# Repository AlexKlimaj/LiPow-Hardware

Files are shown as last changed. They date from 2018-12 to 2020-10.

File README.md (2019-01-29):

# USB-PD-Lipo-Charger-Hardware

https://hackaday.io/project/161771-usb-power-delivery-lipo-battery-charger

This project uses USB Type C with Power Delivery to charge Lithium Polymer batteries. It supports charging 1s-4s batteries and supports balancing for 2s-4s packs. The device supports charging up to 100W (16.8V at 6A).

I got the idea for this project while on a vacation where I only took a single 65W USB C power supply from my Thinkpad to charge the laptop, Nintendo Switch, and cell phone. Having worked with hobby style lithium polymer batteries and bulky chargers, I thought it would be nice to have a small device that could charge LiPo batteries from a USB C power supply.

Input is a USB Type C Port. Charging is done through an XT60 connector and has JST connectors for balancing 2s-4s packs.

The device will be pre-programmed with a fixed max current limit up to 6A. Everything runs automatically and will charge up to the max capability of the connected USB PD power supply if the max current output limit exceeds the input power supply.

The only user feedback is through an RGB LED.

A STM32G0 microcontroller controls runs the system and handles USB PD communication. TI makes the perfect programmable buck boost regulator for this project with the BQ25703A. It accepts input voltage from 3.5V to 24V and the output is meant to charge lithium batteries up to 4s with a current limit of 6.35A. It is programmed through I2C.

A 3.3V linear regulator was needed to provide power for the electronics. The hardest part is that it needs to accept up to 20V on the input due to the power delivery specifications. The IFX25001 from Infineon accepts up to 45V and is a good fit for the project.

I chose to have balance ports for 2s-4s packs for balancing with charging done through an XT60 connector. Originally I was going to support charging through the balance ports, but the typical gauge of wire used for those connections would severely limit the charging current. I also had to design a circuit to automatically route the output from the regulator to the top cell depending on what type of pack was connected. I designed the circuit and thought it was pretty clever, but ultimately, made the decision to reduce complexity and support higher charging current by going with an XT60 connector.

Balancing is controlled by the STM32G0. It monitors the cell voltages using its ADC through voltage dividers to scale the voltage to safe levels. Open drain level shifters were needed to control the PFETs used for discharging. Because of this, it create a large VGS on the PFETs, up to the max of a 4s pack ~16.8V. I needed to find PFETs that could handle 20V VGS.

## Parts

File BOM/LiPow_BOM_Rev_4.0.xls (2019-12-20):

LibRef | Designator | Quantity | Manufacturer | Mfr Part Number | Comment | Mfr Part Description | Footprint | Supplier | Supplier Part Number
30220 | C2, C4, C8, C12, C13, C14, C15, C17, C18, C19, C20, C21, C22, C23, C30, C31, C32, C33, C34, C35, C36, C37 | 22 | TDK Corporation | C2012X5R1V106M085AC | 10uF | CAP CER 10uF ±20% 35V X5R 0805 (2012 Metric) | CAPC0805(2012)155_N | Digi-Key | 445-14419-1-ND
30222 | C5, C9, C38, C40, C47, C48, C49, C50, C51 | 9 | Samsung Electro-Mechanics | CL21B105KBFNNNG | 1uF | CAP CER 1uF ±10% 50V X7R 0805 (2012 Metric) | CAPC0805(2012)155_N | Digi-Key | 1276-6470-1-ND
30221 | C10, C16, C39 | 3 | Samsung Electro-Mechanics | CL21B104KCFNNNE | 0.1uF | CAP CER 0.1uF ±10% 100V X7R 0805 (2012 Metric) | CAPC0805(2012)155_N | Digi-Key | 1276-6840-1-ND
30250 | C24, C25 | 2 | KEMET | C0805C333J3RACTU | 0.033uF | CAP CER 0.033uF ±5% 25V X7R 0805 (2012 Metric) | CAPC0805(2012)155_N | Digi-Key | 399-8069-1-ND
30253 | C26, C27 | 2 | Walsin Technology Corporation | 0805B473J500CT | 0.047uF | CAP CER 0.047uF ±5% 50V X7R 0805 (2012 Metric) | CAPC0805(2012)155_N | Digi-Key | 1292-1583-1-ND
30257 | C41 | 1 | Samsung Electro-Mechanics | CL21A225KAFNNNG | 2.2uF | CAP CER 2.2uF ±10% 25V X5R 0805 (2012 Metric) | CAPC0805(2012)155_N | Digi-Key | 1276-6458-1-ND
30258 | C42 | 1 | Samsung Electro-Mechanics | CL21C330JBANNNC | 33pF | CAP CER 33pF ±5% 50V NPO 0805 (2012 Metric) | CAPC0805(2012)155_N | Digi-Key | 1276-1105-1-ND
30259 | C43 | 1 | Samsung Electro-Mechanics | CL21B182KBANNNC | 1800pF | CAP CER 1800pF ±10% 50V X7R 0805 (2012 Metric) | CAPC0805(2012)155_N | Digi-Key | 1276-2465-1-ND
30262 | C44 | 1 | Wurth Electronics Inc. | 885012007029 | 15pF | CAP CER 15pF ±5% 25V NPO 0805 (2012 Metric) | CAPC0805(2012)155_N | Digi-Key | 732-7828-1-ND
30261 | C45 | 1 | Samsung Electro-Mechanics | CL21B681KBANNNC | 680pF | CAP CER 680pF ±10% 50V X7R 0805 (2012 Metric) | CAPC0805(2012)155_N | Digi-Key | 1276-2538-1-ND
30264 | C46 | 1 | Samsung Electro-Mechanics | CL21C101JC61PNC | 100pF | CAP CER 100pF ±5% 100V NPO 0805 (2012 Metric) | CAPC0805(2012)155_N | Digi-Key | 1276-2569-1-ND
30239 | D1, D2, D4, D5, D6, D7, D8 | 7 | ON Semiconductor | ESD9X5.0ST5G | ESD9X5.0ST5G | TVS DIODE 5V 12.3V SOD923 | SOD-923 | Digi-Key | ESD9X5.0ST5GOSCT-ND
30242 | D3 | 1 | Everlight Electronics Co Ltd | EAST1616RGBA3 | EAST1616RGBA3 | LED RGB CLEAR 4SMD | EAST1616RGBA3 | Digi-Key | 1080-1550-1-ND
30231 | F1 | 1 | Vishay Beyschlag | MFU0603FF05000P100 | MFU0603FF05000P100 | FUSE BOARD MOUNT 5A 32VDC 0603 | Fuse 0603 | Digi-Key | MFU06035.00CT-ND
30530 | J1 | 1 | Molex | 2012670005 | 2012670005 | CONN RCP USB3.1 TYPEC 24P SMD RA | 2012670005 | Digi-Key | WM17992CT-ND
30040 | J2 | 1 | JST Sales America Inc. | S5B-XH-A(LF)(SN) | S5B-XH-A 5 Pin Header | CONN HEADER XH SIDE 5POS 2.5MM | S5B-XH-A | Digi-Key | 455-2242-ND
30228 | J3 | 1 | JST Sales America Inc. | S4B-XH-A(LF)(SN) | S4B-XH-A(LF)(SN) | CONN HEADER XH SIDE 4POS 2.5MM | S4B-XH-A | Digi-Key | 455-2243-ND
30229 | J4 | 1 | JST Sales America Inc. | S3B-XH-A(LF)(SN) | S3B-XH-A(LF)(SN) | CONN HEADER XH SIDE 3POS 2.5MM | S3B-XH-A | Digi-Key | 455-2250-ND
30265 | J6 | 1 | AMASS | XT60PW-M | XT60PW-M | Socket; DC supply; XT60; male; PIN:2; on PCBs; THT; Colour: yellow | XT60PW-M | tme.eu | XT60PW-M
30252 | L1 | 1 | Murata Electronics North America | DD1217AS-H-2R2N=P3 | 2.2uH | INDUCTOR 2.2uH ±30% 8.7A Nonstandard | DD1217AS-H-2R2N=P3 | Digi-Key | 490-13196-1-ND
30266 | Q1, Q3, Q4, Q5, Q6 | 5 | Diodes Incorporated | DMP3056L-7 | Vgs(max)=+-25V | MOSFET P-CH 30V 4.3A SOT23 | Diode SOT23 PMOS | Digi-Key | DMP3056L-7DICT-ND
30255 | Q2 | 1 | Micro Commercial Co | MCQ4435-TP | MCQ4435-TP | P-CHANNEL MOSFET, SOP-8 PACKAGE | SOP-8 PMOS Micro Commercial | Digi-Key | MCQ4435-TPMSCT-ND
30247 | Q8, Q9, Q10, Q11 | 4 | Nexperia USA Inc. | NX7002AK,215 | NX7002AK,215 | MOSFET N-CH 60V TO-236AB | TO-236AB (SOT23) | Digi-Key | 1727-1289-1-ND
30251 | Q12, Q13, Q14, Q15 | 4 | Rohm Semiconductor | RQ3E080BNTB | RQ3E080BNTB | MOSFET N-CH 30V 8A HSMT8 | RQ3E080BNTB | Digi-Key | RQ3E080BNTBCT-ND
30227 | R1, R5, R6, R7, R8, R18, R25, R27, R29, R31, R36, R37, R38, R39, R50, R51, R53, R57 | 18 | Bourns Inc. | CR0805-FX-1002ELF | 10K | RES 10K Ohm ±1% 1/8W 0805 (2012 Metric) | RESC0805(2012)_L | Digi-Key | CR0805-FX-1002ELFCT-ND
30236 | R3, R4, R13, R14, R15, R20 | 6 | TE Connectivity Passive Product | CRGCQ0805F1K2 | 1.2K | RES 1.2K Ohm ±1% 1/8W 0805 (2012 Metric) | RESC0805(2012)_L | Digi-Key | A129750CT-ND
30294 | R9, R12, R19 | 3 | Stackpole Electronics Inc. | RMCF0805FG5K36 | 5.36K | RES 5.36K Ohm ±1% 1/8W 0805 (2012 Metric) | RESC0805(2012)_L | Digi-Key | RMCF0805FG5K36CT-ND
30295 | R10 | 1 | Stackpole Electronics Inc. | RMCF0805FT3K57 | 3.57K | RES 3.57K Ohm ±1% 1/8W 0805 (2012 Metric) | RESC0805(2012)_L | Digi-Key | RMCF0805FT3K57CT-ND
30238 | R11, R21, R44, R56, R58 | 5 | Bourns Inc. | CR0805-J/-000ELF | 0 | RES 0 Ohm Jumper 1/8W 0805 (2012 Metric) | RESC0805(2012)_L | Digi-Key | CR0805-J/-000ELFCT-ND
30235 | R16, R17 | 2 | Stackpole Electronics Inc. | RMCF0805FT3K30 | 3.3K | RES 3.3K Ohm ±1% 1/8W 0805 (2012 Metric) | RESC0805(2012)_L | Digi-Key | RMCF0805FT3K30CT-ND
30439 | R26, R28, R30, R32 | 4 | Rohm Semiconductor | LTR18EZPJ470 | 47 | RES SMD 47 OHM 3/4W 1206 WIDE | Wide 1206 (3216 Metric) | Digi-Key | RHM47ZCT-ND
30243 | R33 | 1 | Stackpole Electronics Inc. | RMCF0805JT300R | 300 | RES 300 Ohm ±5% 1/8W 0805 (2012 Metric) | RESC0805(2012)_L | Digi-Key | RMCF0805JT300RCT-ND
30244 | R34 | 1 | Stackpole Electronics Inc. | RMCF0805JT75R0 | 75 | RES 75 Ohm ±5% 1/8W 0805 (2012 Metric) | RESC0805(2012)_L | Digi-Key | RMCF0805JT75R0CT-ND
30245 | R35 | 1 | Bourns Inc. | CR0805-JW-101ELF | 100 | RES 100 Ohm ±5% 1/8W 0805 (2012 Metric) | RESC0805(2012)_L | Digi-Key | CR0805-JW-101ELFCT-ND
30248 | R40, R41 | 2 | Ohmite | LVT12R0100FER | 0.01 | RES 0.01 Ohm ±1% 1W 1206 (3216 Metric) | RES1206 | Digi-Key | LVT12R0100FERCT-ND
30249 | R42, R43 | 2 | Stackpole Electronics Inc. | RMCF0805FT4R99 | 4.99 | RES 4.99 Ohm ±1% 1/8W 0805 (2012 Metric) | RESC0805(2012)_L | Digi-Key | RMCF0805FT4R99CT-ND
30256 | R45, R46, R47, R49 | 4 | Stackpole Electronics Inc. | RMCF0805FT10R0 | 10 | RES 10 Ohm ±1% 1/8W 0805 (2012 Metric) | RESC0805(2012)_L | Digi-Key | RMCF0805FT10R0CT-ND
30260 | R52, R54 | 2 | Yageo | RC0805FR-0740K2L | 40.2K | RES 40.2K Ohm ±1% 1/8W 0805 (2012 Metric) | RESC0805(2012)_L | Digi-Key | 311-40.2KCRCT-ND
30263 | R55 | 1 | Stackpole Electronics Inc. | RMCF0805FT137K | 137K | RES 137K Ohm ±1% 1/8W 0805 (2012 Metric) | RESC0805(2012)_L | Digi-Key | RMCF0805FT137KCT-ND
30269 | U2 | 1 | STMicroelectronics | STM32G071CBT6 | STM32G071CBT6 | MAINSTREAM ARM CORTEX-M0+ MCU WI | ST LQFP48 | Digi-Key | 497-18342-ND
30225 | U3 | 1 | Texas Instruments | BQ25703ARSNR | BQ25703ARSNR | BQ25703ARSNR | QFN40P400X400X80_HS-33N | Digi-Key | 296-47649-1-ND
30240 | U5 | 1 | Infineon Technologies | IFX25001MEV33HTSA1 | IFX25001MEV33HTSA1 | IC REG LIN 3.3V 400MA SOT223-4 | PG-SOT223-4 Infineon | Digi-Key | IFX25001MEV33HTSA1CT-ND

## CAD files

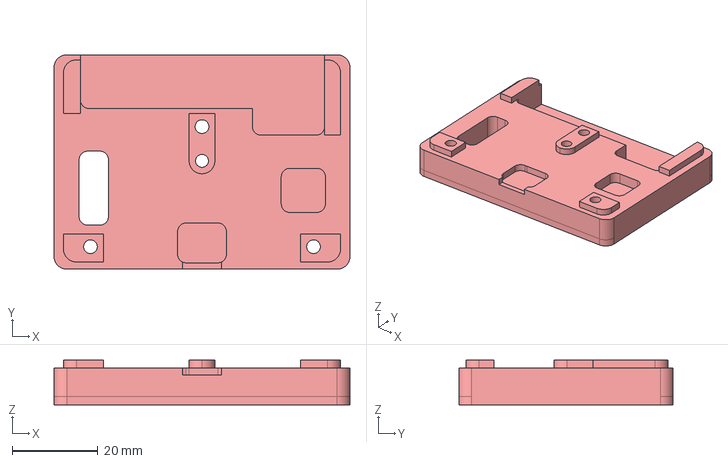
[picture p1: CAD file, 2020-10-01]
Case/CNC Case/Top Case CNC V1.0.step
69.0 x 50.0 x 10.4 mm

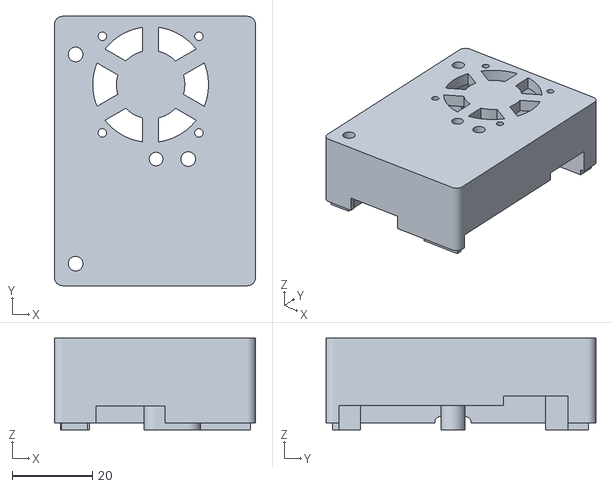
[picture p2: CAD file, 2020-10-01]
Case/Fan Case/Top Case Fan 1.0.stl
50.0 x 67.0 x 22.8

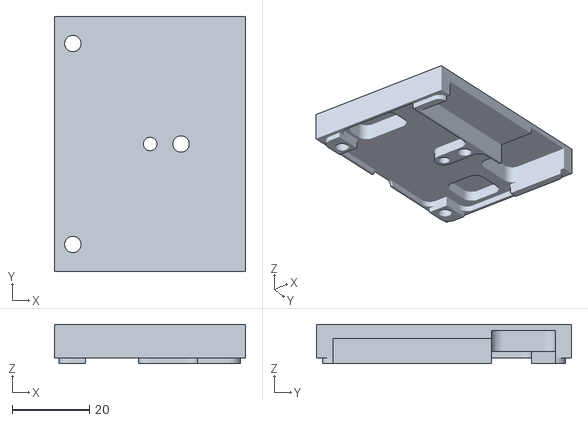
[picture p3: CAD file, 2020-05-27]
Case/Regular Case/LiPow Top Case Rev 0.6.stl
49.5 x 66.0 x 10.2

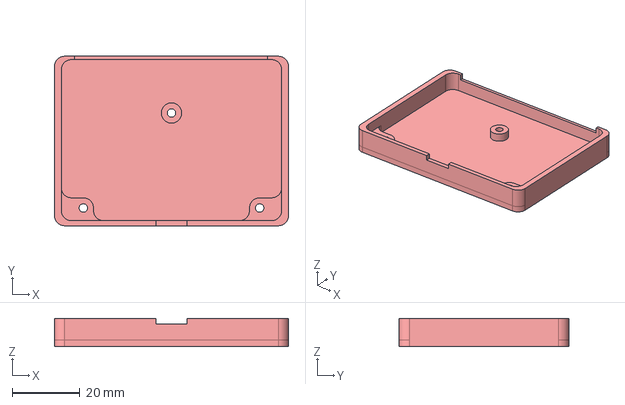
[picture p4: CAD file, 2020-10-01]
Case/CNC Case/Bottom Case CNC V1.0.step
69.0 x 50.0 x 8.31 mm

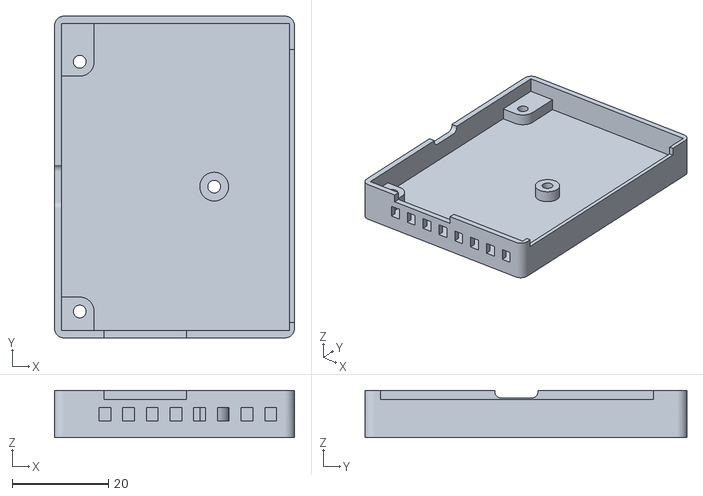
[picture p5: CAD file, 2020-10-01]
Case/Fan Case/Bottom Case Fan 1.0.stl
50.0 x 67.0 x 9.81

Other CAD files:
Case/Regular Case/LiPow Bottom Case Rev 0.6.stl
Case/Regular Case/LiPow Top Case Rev 0.5 Debug.stl

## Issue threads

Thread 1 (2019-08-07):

Break out VSYS?

nevercast, 2019-08-07:
Hello Alex,

I really like this board design and I've checked out your product on Tindie. The BQ25703ARSNR is a very nice chip too.

I'm hoping you might consider another product, or a revision to this product, where VSYS is provided on a board header also so that I may use LiPow as both a charger and power delivery to my system.

I would like to use something similar to LiPow for in-system charging of my robot project as well as powering the system. The BQ25703ARSNR has some nice features included powering the system from charge cable and supplimenting with battery power when available.

Since the STM32G0 occupies the I2C and having two hosts talk to the BQ25703ARSNR could be bad, I would consider making the UART protocol machine readable, but that would be a software adaption and I see that is open source.

Do you have any plans in the future to provide system power from the LiPow?

Thanks again for your time on this project, it really is a nicely done board.

AlexKlimaj, 2019-08-08:
Hi, thanks for the feedback. I don't have any plans at the moment for a revision of LiPow. I do have a board I've designed that is purely a breakout for the BQ25703ARSNR. It is sitting in a box waiting to be assembled. Unfortunately I didn't break out VSYS on that either. But there are lots of bulk capacitors on VSYS you could tack onto. Same with LiPow.
https://github.com/AlexKlimaj/BQ25703A_Module

It would be pretty easy to improve the firmware to have everything controllable over the UART.

nevercast, 2019-08-11:
Hello again Alex,

Thanks for the link to your breakout board. Are the only board layout files in the manufacturing docs? Do you have gerbers?

Kind regards

AlexKlimaj, 2019-08-12:
I can send you the gerbers if you are interested in building your own. I could also send you PCBs if you are interested.

nevercast, 2019-08-12:
I would be interested in building my own, and probably merging the module with existing hardware that I have for driving motors / servos. Shall we continue this via email?

x893, 2020-02-19:
Hello Alex,
Thank you for LiPow and BQ25703 boards design. I want order boards for soldering (i have BQ... and other chips). Can you commit or send me directly gerber files ?

Best regards
Mitek

AlexKlimaj, 2020-02-20:
@x893 send me an email at alex@arkelectron.com

x893, 2020-02-22:
@AlexKlimaj please send to x893.00@gmail.com
Thanks

Closed 2020-02-20.

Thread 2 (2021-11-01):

What different BAT pin and CELL_4S/CELL_3S pin?

jecelyin, 2021-11-01:
Hi,
   I use 3s of 18650 batteries to charge, how to connect is correct?

Thanks!

---------- BAT or CELL_3S ?
🔋
---------- CELL_2S
🔋
---------- CELL_1S
🔋
---------- GND

AlexKlimaj, 2021-11-01:
You need cell 3s connected to the 3s input and BAT to charge. If it is just connected to the balance port, it will only balance.

jecelyin, 2021-11-01:
---------- BAT pin and CELL_3S pin connect to here?
🔋
---------- CELL_2S
🔋
---------- CELL_1S
🔋
---------- GND

AlexKlimaj, 2021-11-02:
That is correct.

jecelyin, 2021-11-02:
Thanks

Closed 2021-11-02.

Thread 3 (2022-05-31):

No Gerber file?

bigjoncoop, 2022-05-31:
I see you have the BOM files but I do not see a gerber file for the PCB...

The schematics or just PDF files. So I'm not quite sure what the purpose of the GitHub is for?

Anyone that's reading this I'll go ahead and spend a bunch of hours recreating the schematics and designing a new pcb and uploads all the files, including a gerber file. If the BOM changes due to the chip shortage at the moment I'll make a note.

AlexKlimaj, 2022-05-31:
Yes that is intentional.

Closed 2022-05-31.

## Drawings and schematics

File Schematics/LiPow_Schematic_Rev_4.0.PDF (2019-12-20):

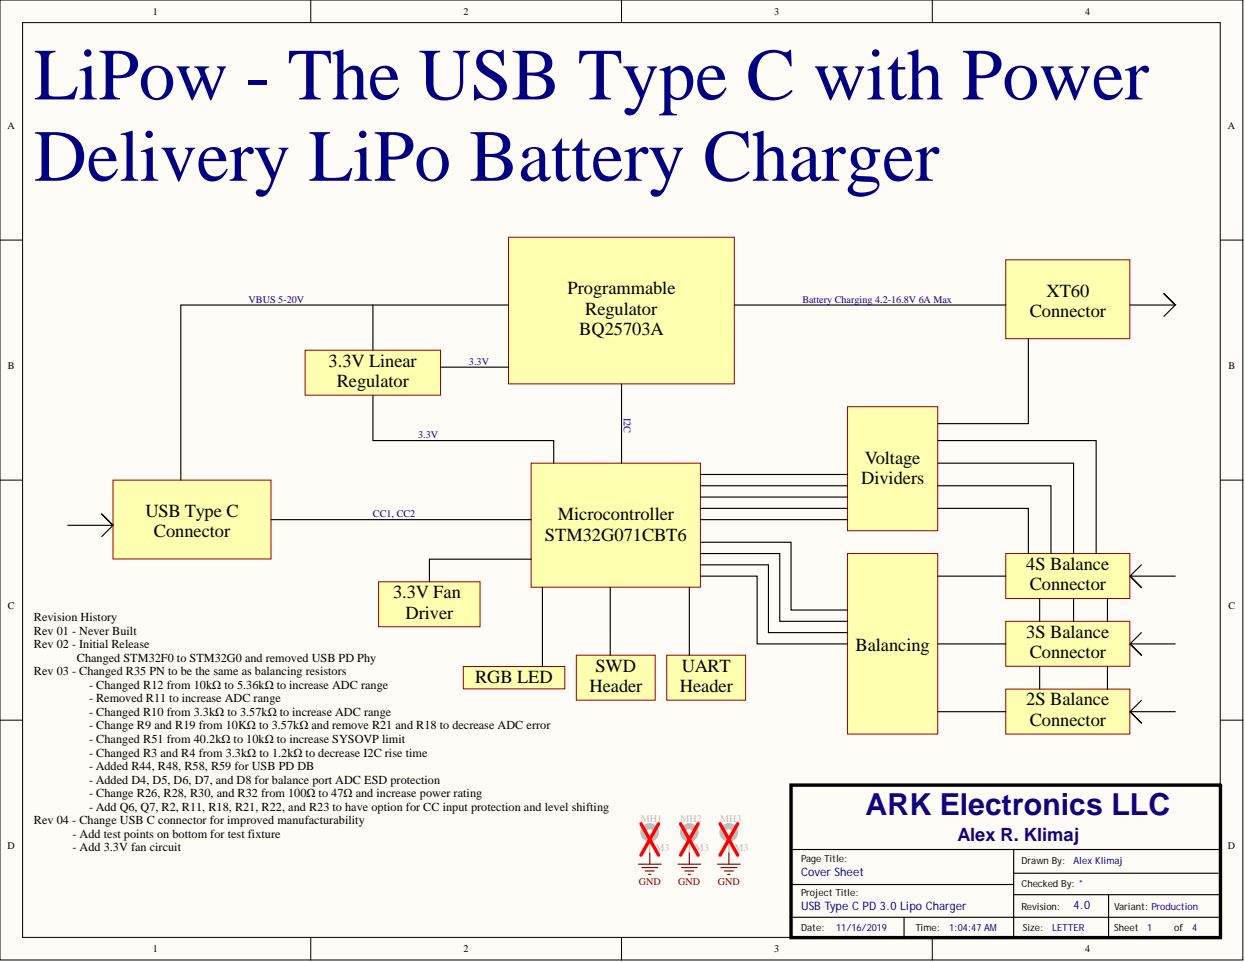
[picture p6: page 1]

LiPow - The USB Type C with Power
Delivery LiPo Battery Charger

Changed STM32F0 to STM32G0 and removed USB PD Phy

Rev 03 - Changed R35 PN to be the same as balancing resistors

- Changed R12 from 10kΩ to 5.36kΩ to increase ADC range
- Removed R11 to increase ADC range
- Changed R10 from 3.3kΩ to 3.57kΩ to increase ADC range
- Change R9 and R19 from 10KΩ to 3.57kΩ and remove R21 and R18 to decrease ADC error
- Changed R51 from 40.2kΩ to 10kΩ to increase SYSOVP limit
- Changed R3 and R4 from 3.3kΩ to 1.2kΩ to decrease I2C rise time
- Added R44, R48, R58, R59 for USB PD DB
- Added D4, D5, D6, D7, and D8 for balance port ADC ESD protection
- Change R26, R28, R30, and R32 from 100Ω to 47Ω and increase power rating
- Add Q6, Q7, R2, R11, R18, R21, R22, and R23 to have option for CC input protection and level shifting

Rev 04 - Change USB C connector for improved manufacturability

- Add test points on bottom for test fixture
- Add 3.3V fan circuit

Project Title:
USB Type C PD 3.0 Lipo Charger

Revision: | Variant: Production

Date: 11/16/2019 | Time: 1:04:47 AM | Size: LETTER | Sheet of

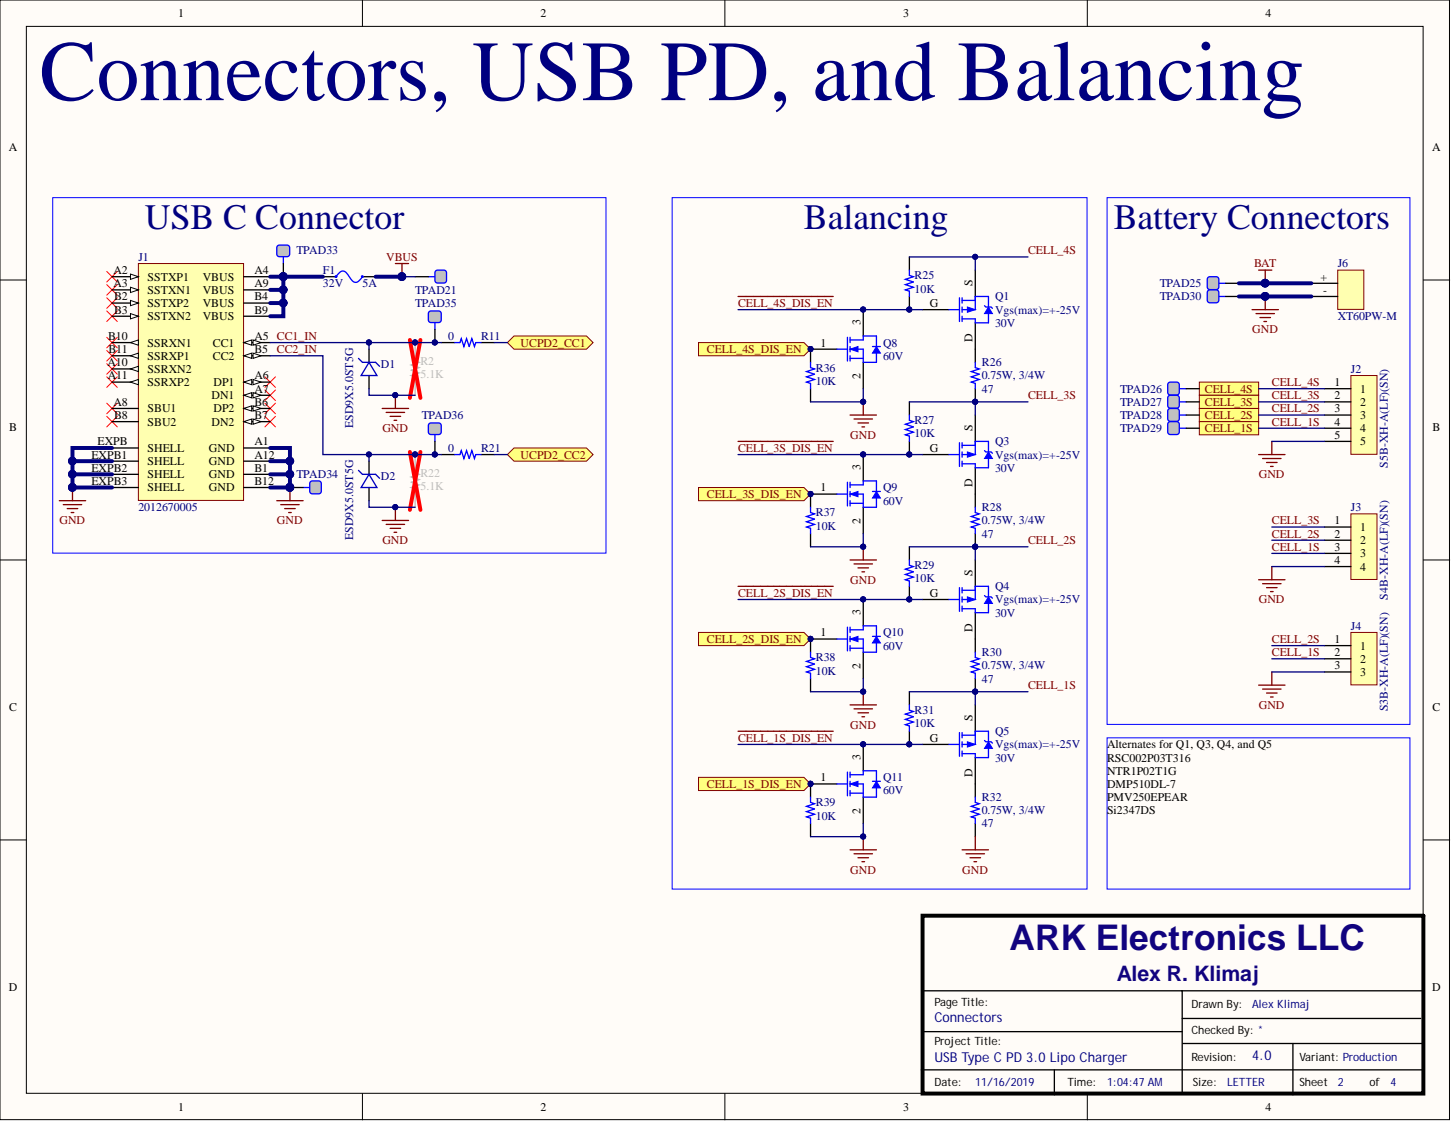
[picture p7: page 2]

Connectors, USB PD, and Balancing

GND
ARK Electronics LLC Alex R. Klimaj

Title:
Type C PD 3.0 Lipo Charger

Variant : Production 2 4

Date: 11/16/2019 | 1:04:47 A M | Size:

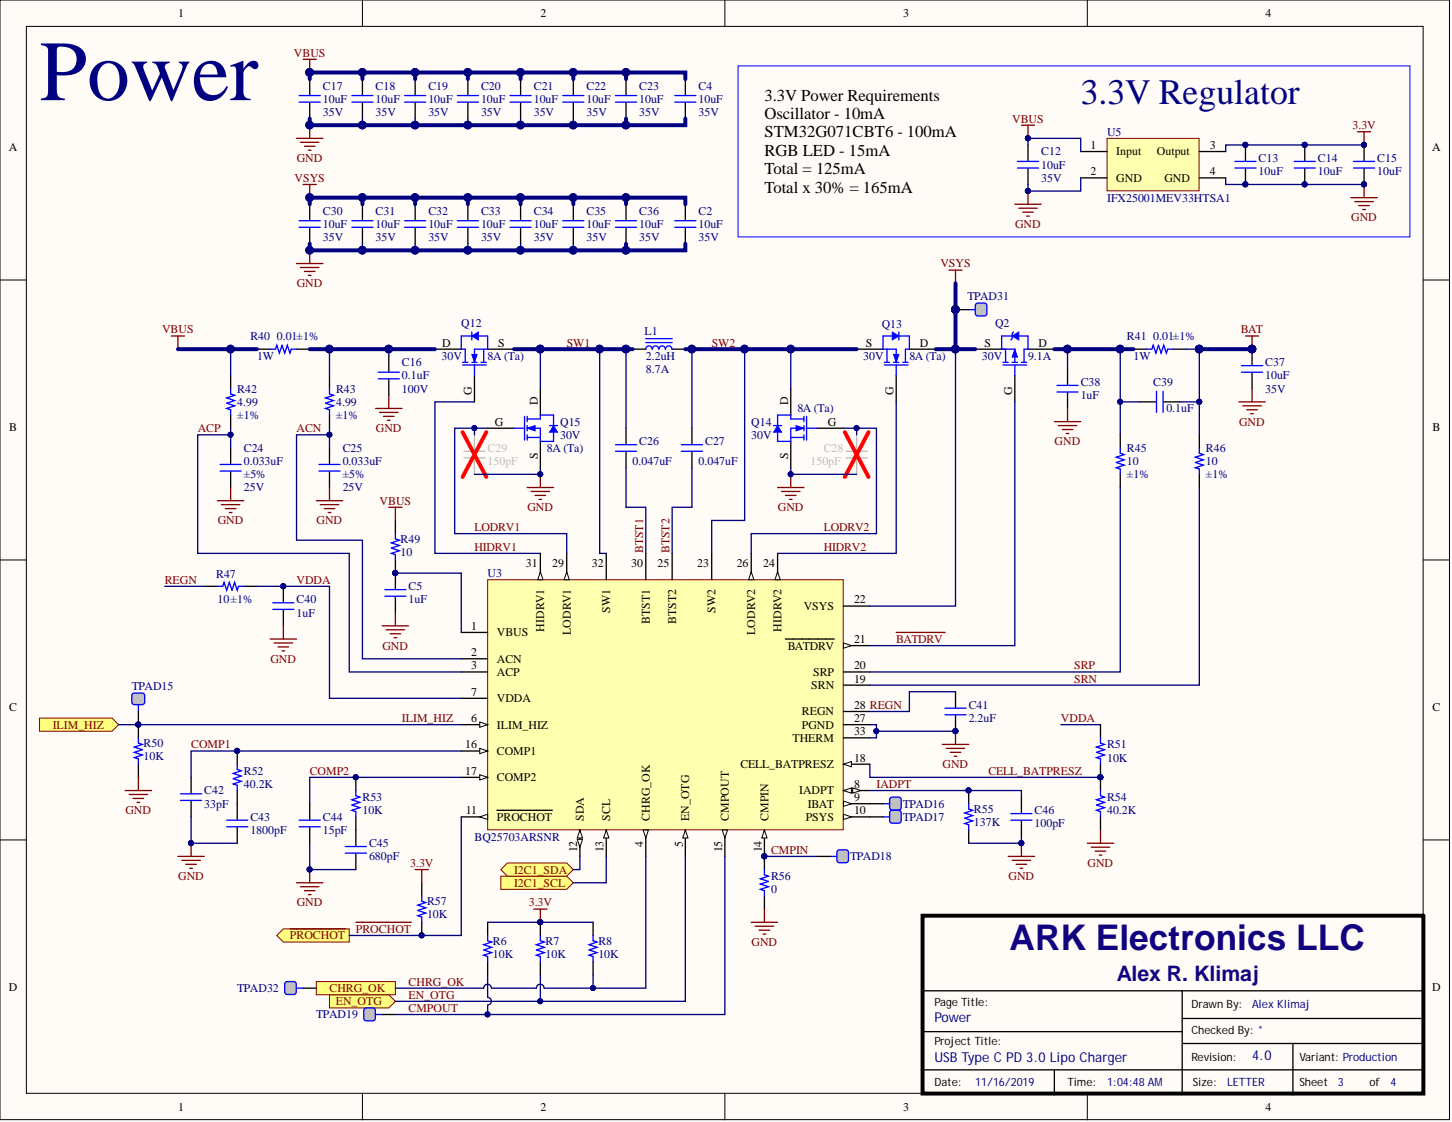
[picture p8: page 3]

R52 COMP2 | COMP2 17

CELL_BATPRESZ

R53 | IADPT

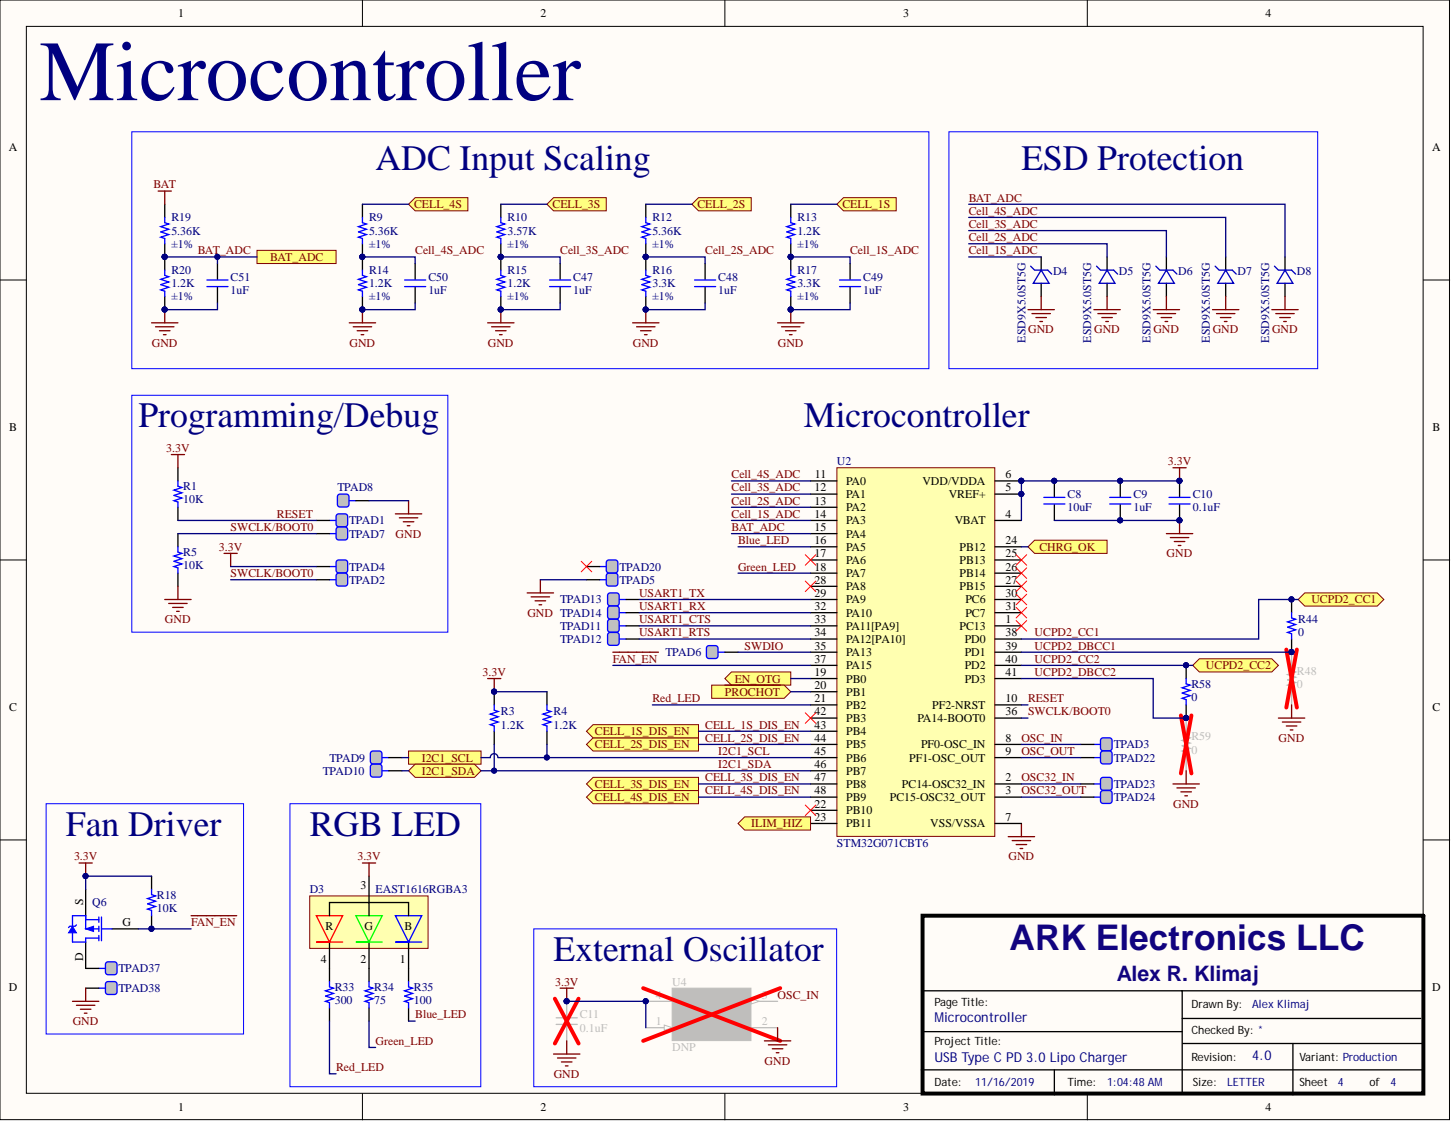
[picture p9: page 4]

11/16/2019 | 1:04:48 AM | Size:

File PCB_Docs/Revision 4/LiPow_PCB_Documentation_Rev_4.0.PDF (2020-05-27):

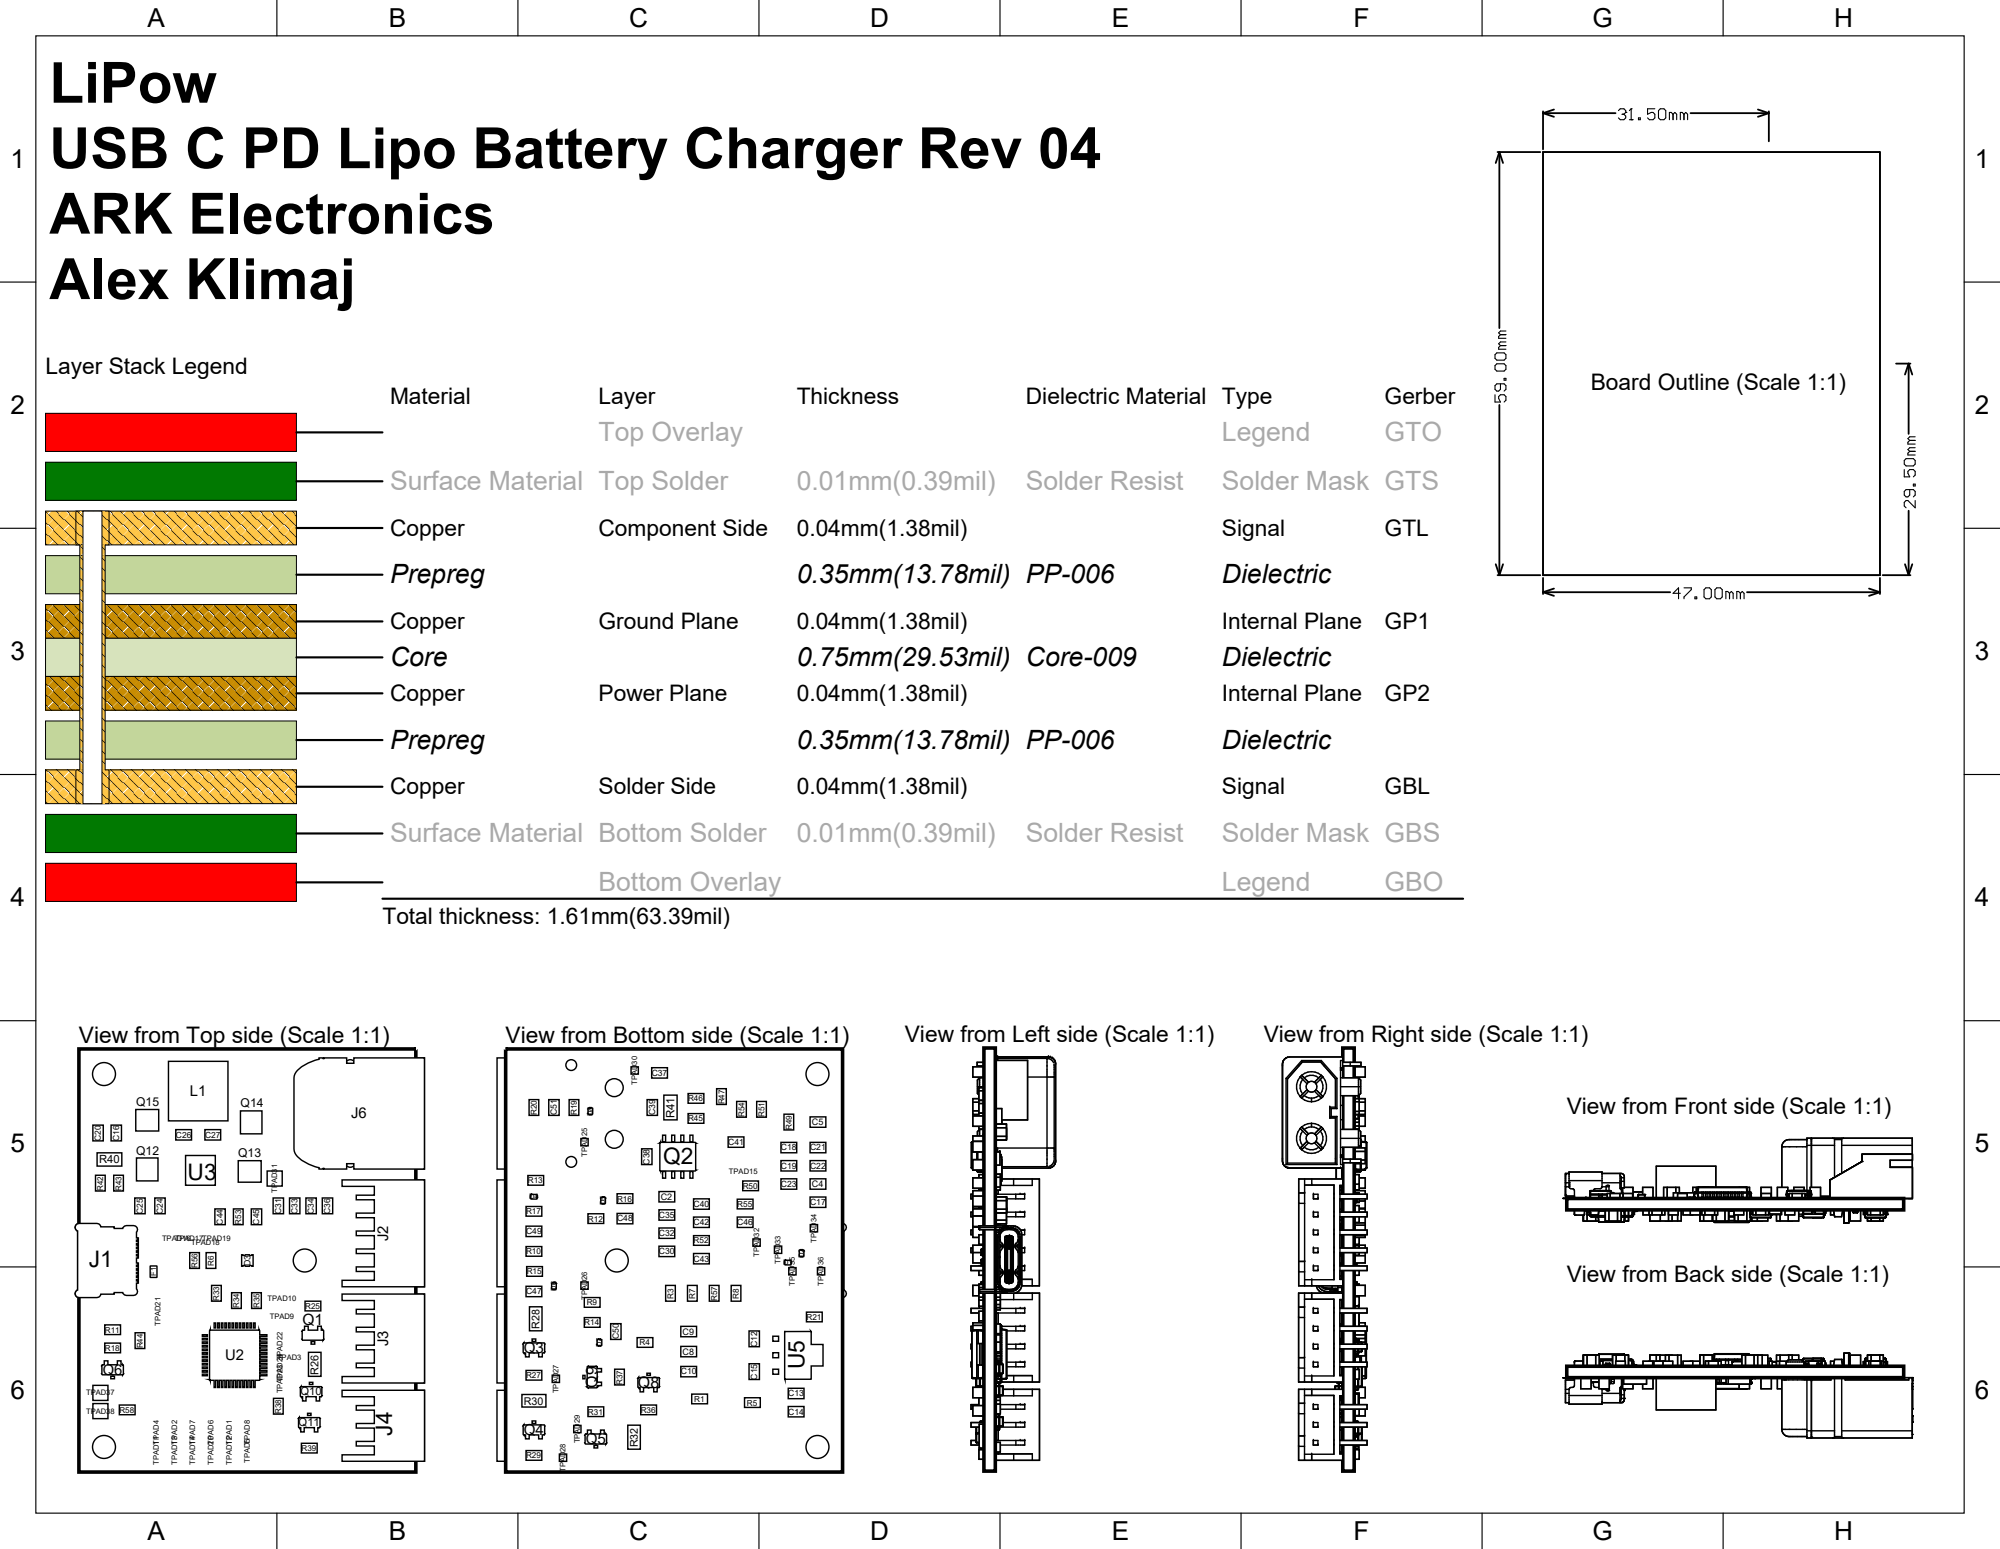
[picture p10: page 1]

LiPow
USB C PD Lipo Battery Charger Rev 04
ARK Electronics
Alex Klimaj

View from Top side (Scale 1:1)

View from Front side (Scale 1:1)

View from Back side (Scale 1:1)

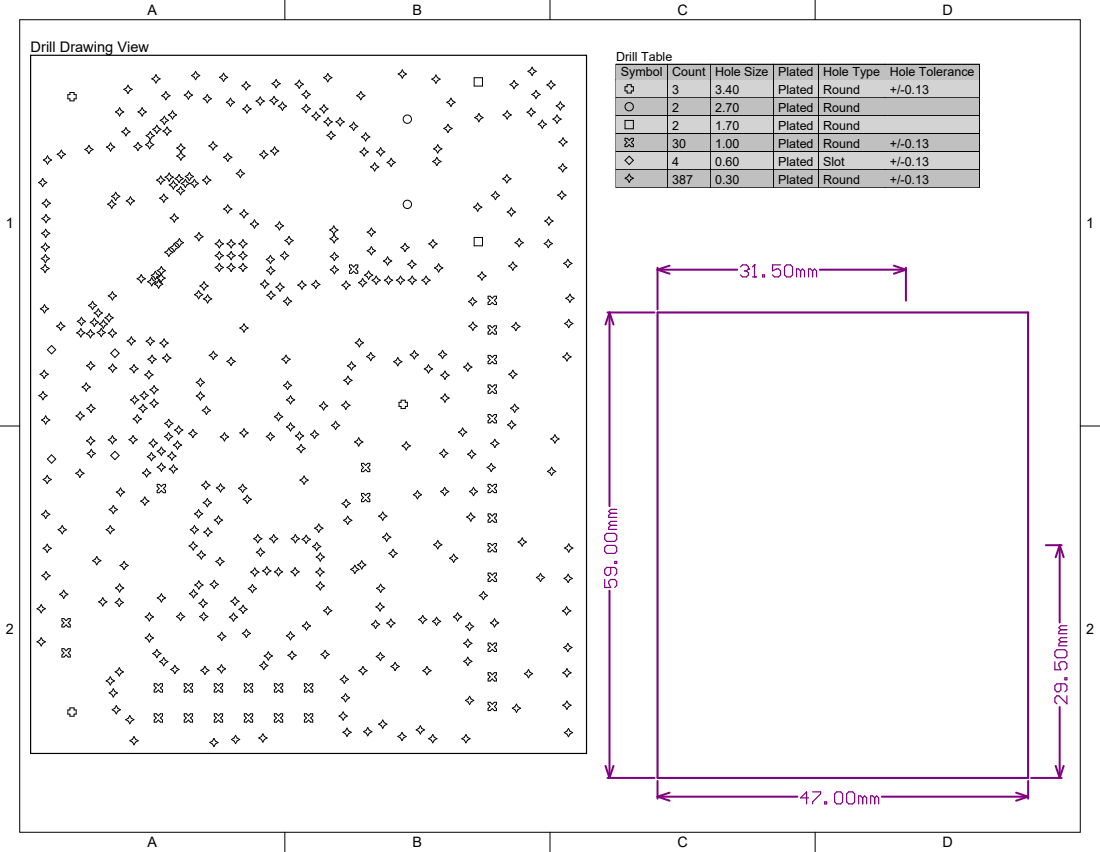
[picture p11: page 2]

Symbol | Count | Hole Size | Plated | Hole Type | Hole Tolerance

3 | 3.40 | Plated | Round | +/-0.13
2 | 2.70 | Plated | Round
2 | 1.70 | Plated | Round
30 | 1.00 | Plated | Round | +/-0.13
4 | 0.60 | Plated | Slot | +/-0.13
387 | 0.30 | Plated | Round | +/-0.13

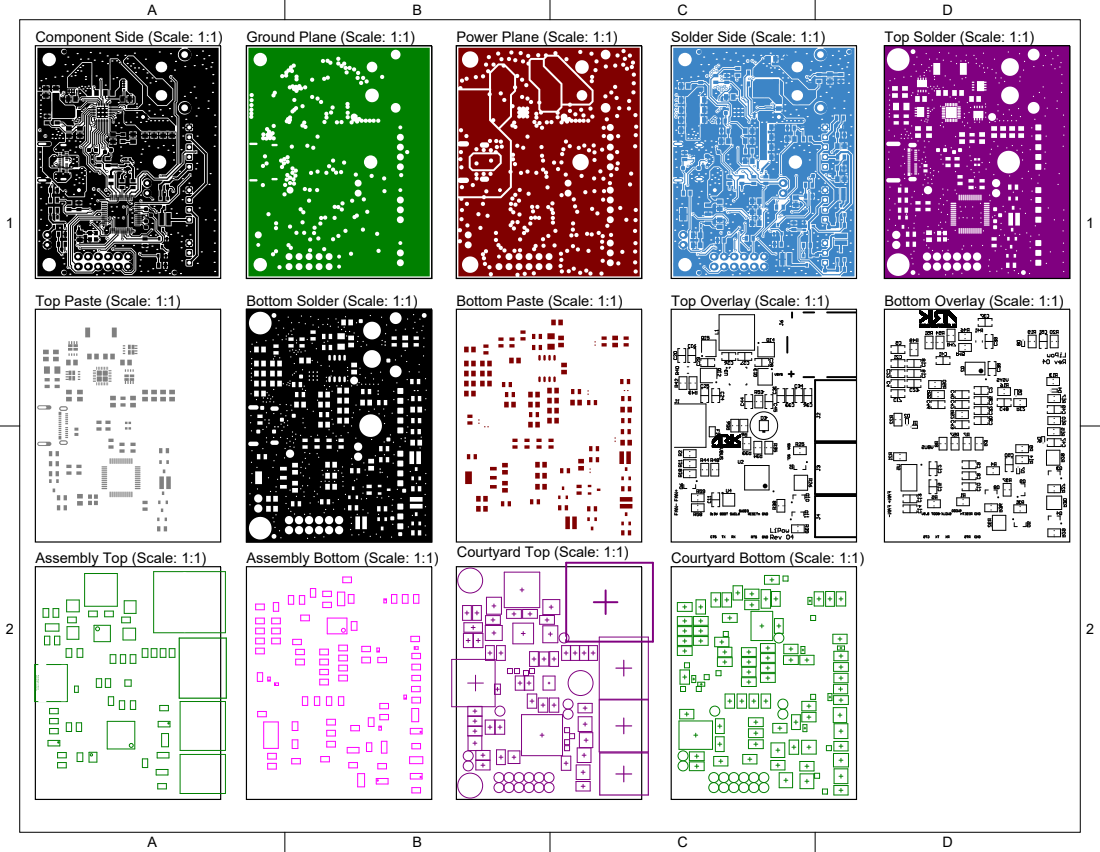
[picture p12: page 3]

Courtyard Bottom (Scale: 1:1) Courtyard Top (Scale: 1:1)

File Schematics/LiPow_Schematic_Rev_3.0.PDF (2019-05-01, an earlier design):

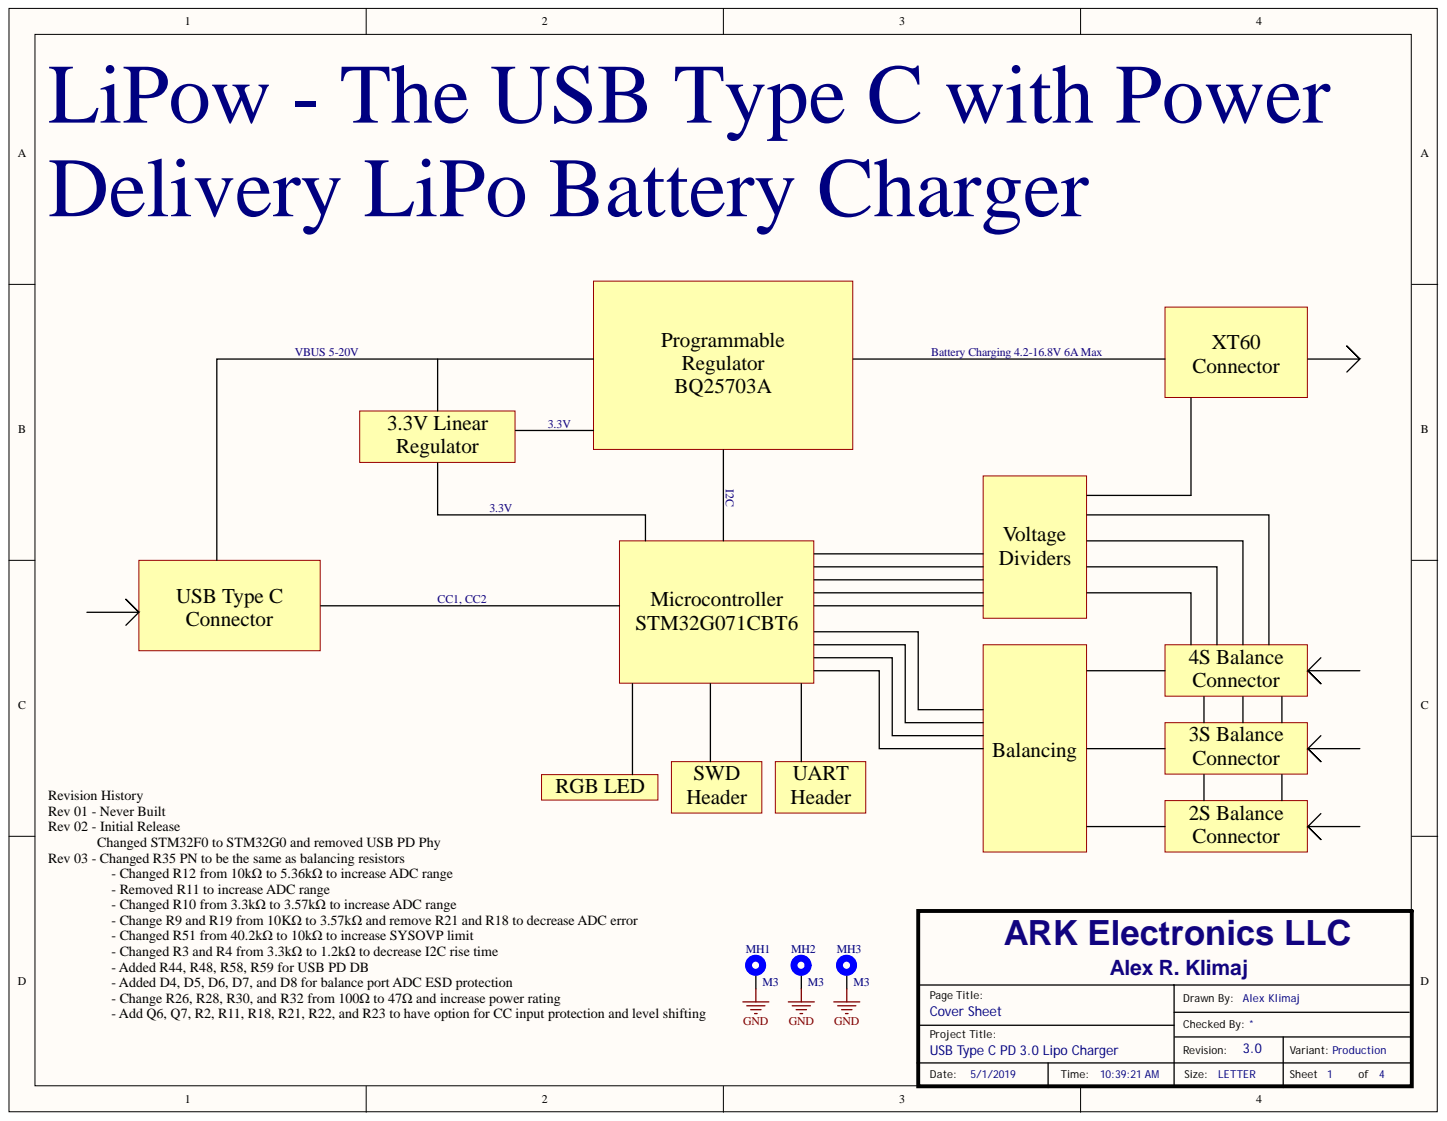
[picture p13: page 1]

LiPow - The USB Type C with Power
Delivery LiPo Battery Charger

Changed STM32F0 to STM32G0 and removed USB PD Phy

Rev 03 - Changed R35 PN to be the same as balancing resistors

- Changed R12 from 10kΩ to 5.36kΩ to increase ADC range
- Removed R11 to increase ADC range
- Changed R10 from 3.3kΩ to 3.57kΩ to increase ADC range
- Change R9 and R19 from 10KΩ to 3.57kΩ and remove R21 and R18 to decrease ADC error
- Changed R51 from 40.2kΩ to 10kΩ to increase SYSOVP limit
- Changed R3 and R4 from 3.3kΩ to 1.2kΩ to decrease I2C rise time
- Added R44, R48, R58, R59 for USB PD DB
- Added D4, D5, D6, D7, and D8 for balance port ADC ESD protection
- Change R26, R28, R30, and R32 from 100Ω to 47Ω and increase power rating
- Add Q6, Q7, R2, R11, R18, R21, R22, and R23 to have option for CC input protection and level shifting

Project Title:
USB Type C PD 3.0 Lipo Charger

Revision: | Variant: Production

Date: 5/1/2019 | Time: 10:39:21 AM | Size: LETTER | Sheet of

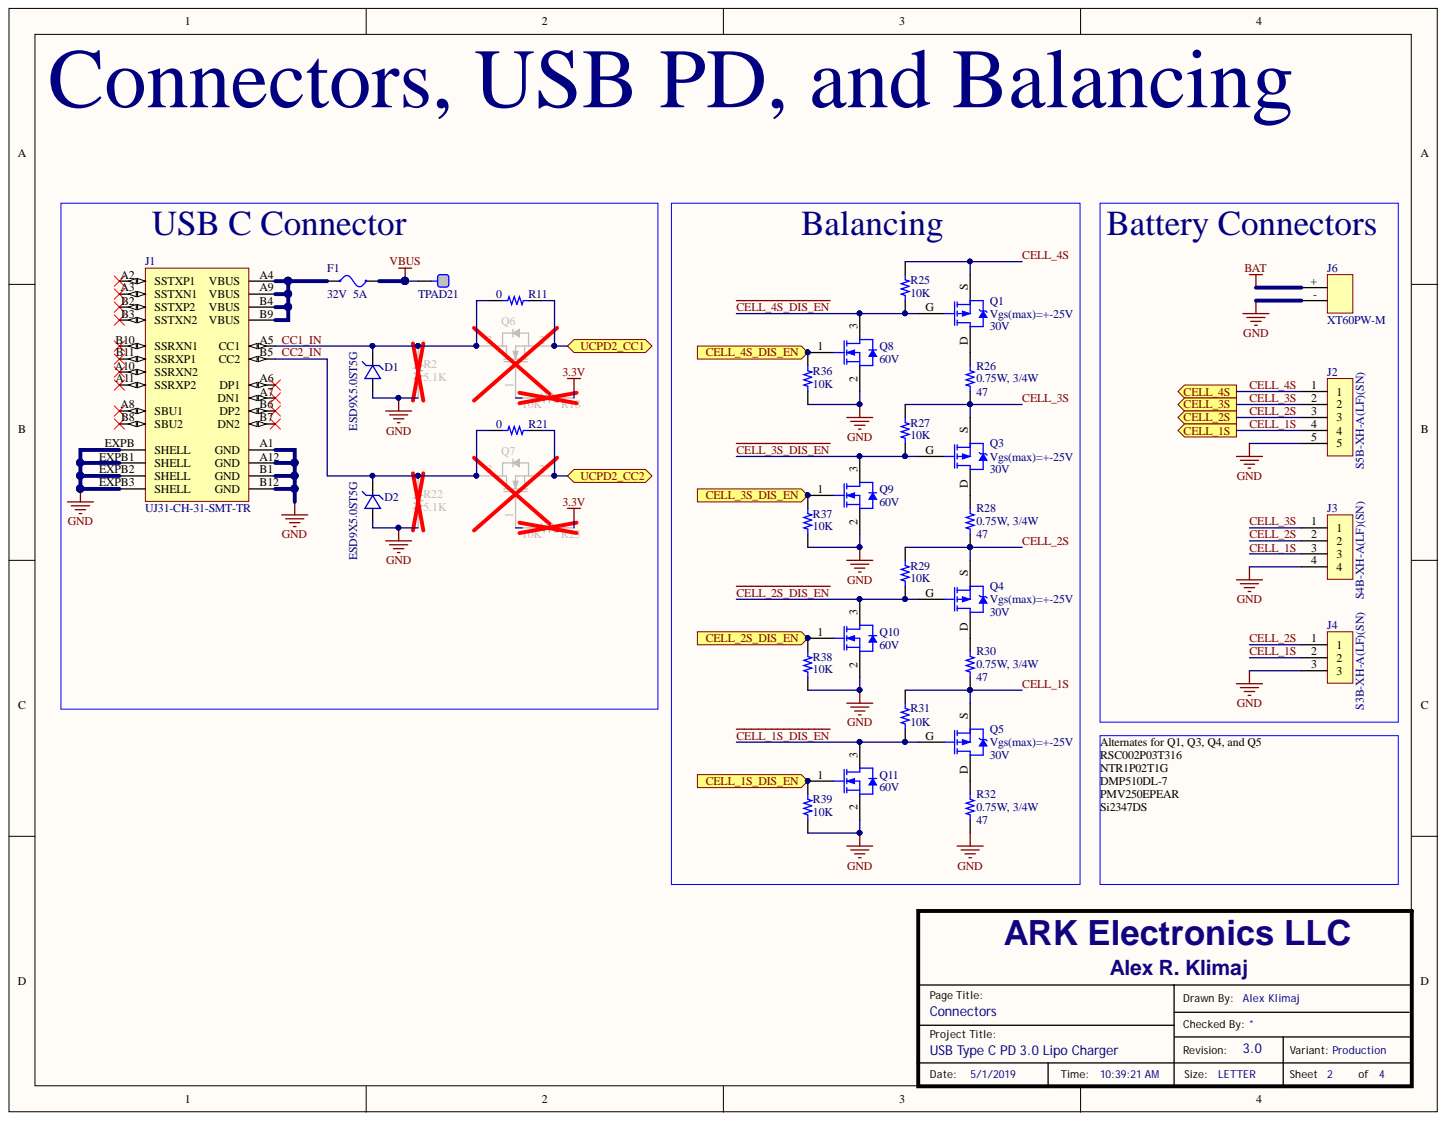
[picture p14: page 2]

Connectors, USB PD, and Balancing 32V 5A

ARK Electronics LLC Alex R. Klimaj

3. | Production 2 4

Date: 5/1/2019 | Time: 10:39:21 AM | Size: LETT ER | Sheet of

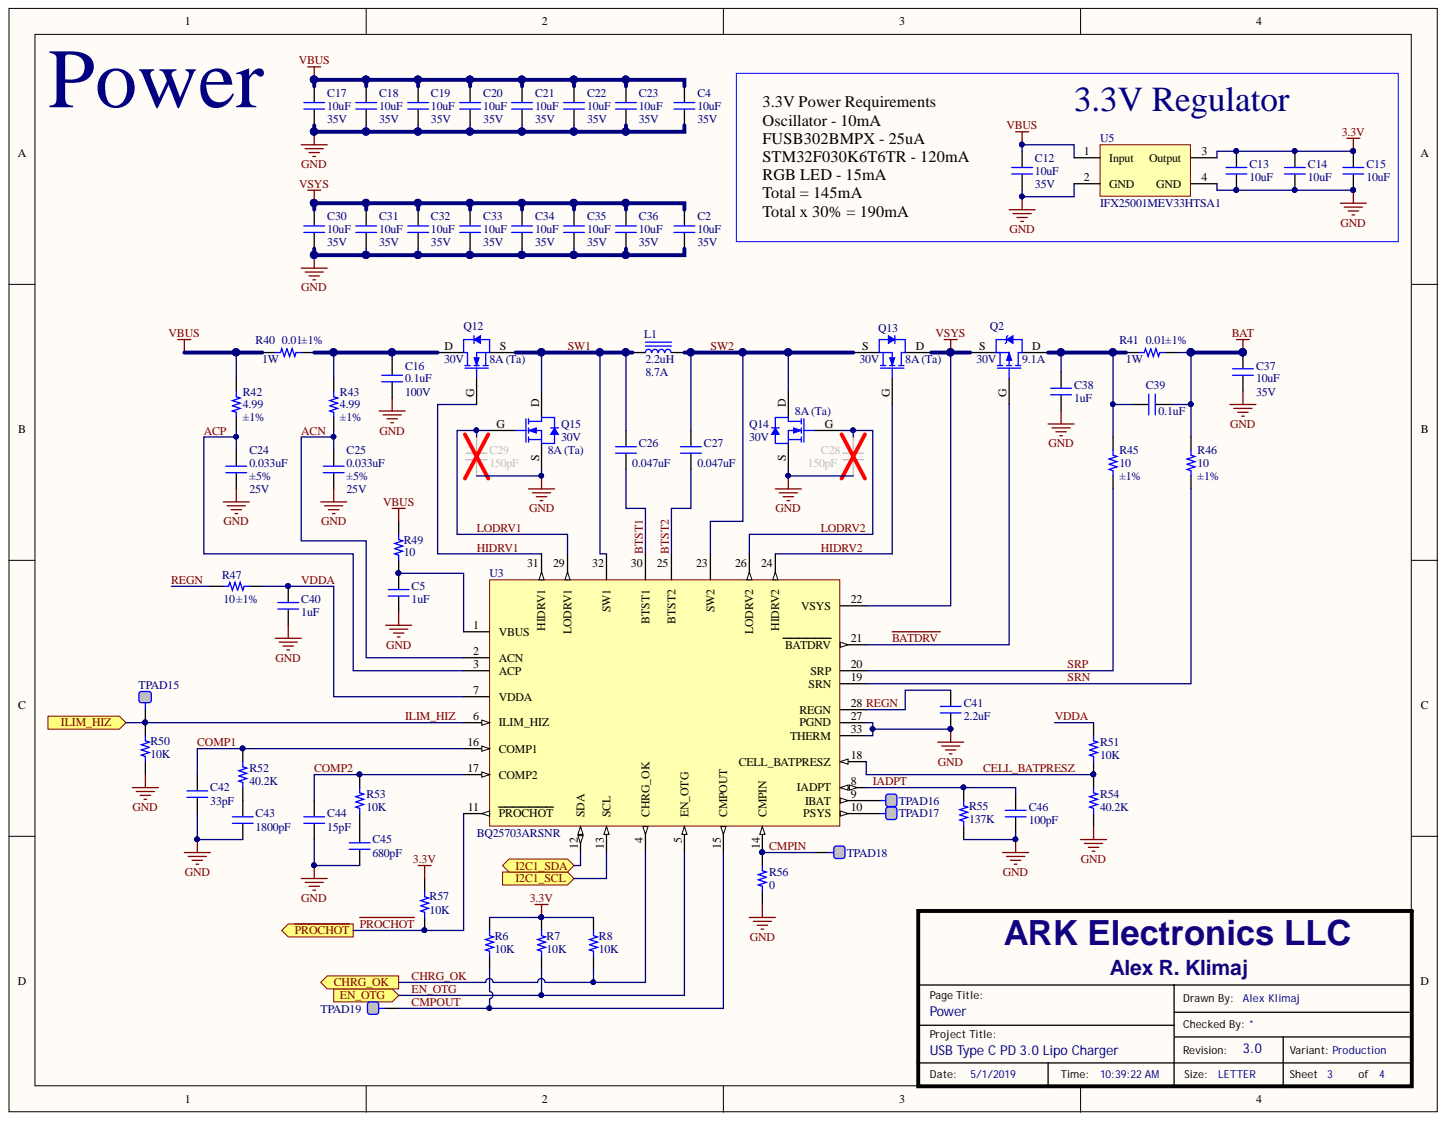
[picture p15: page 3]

SRP

VDDA 7 | | SRN

R52 COMP2 | COMP2 17

R53 | IADPT

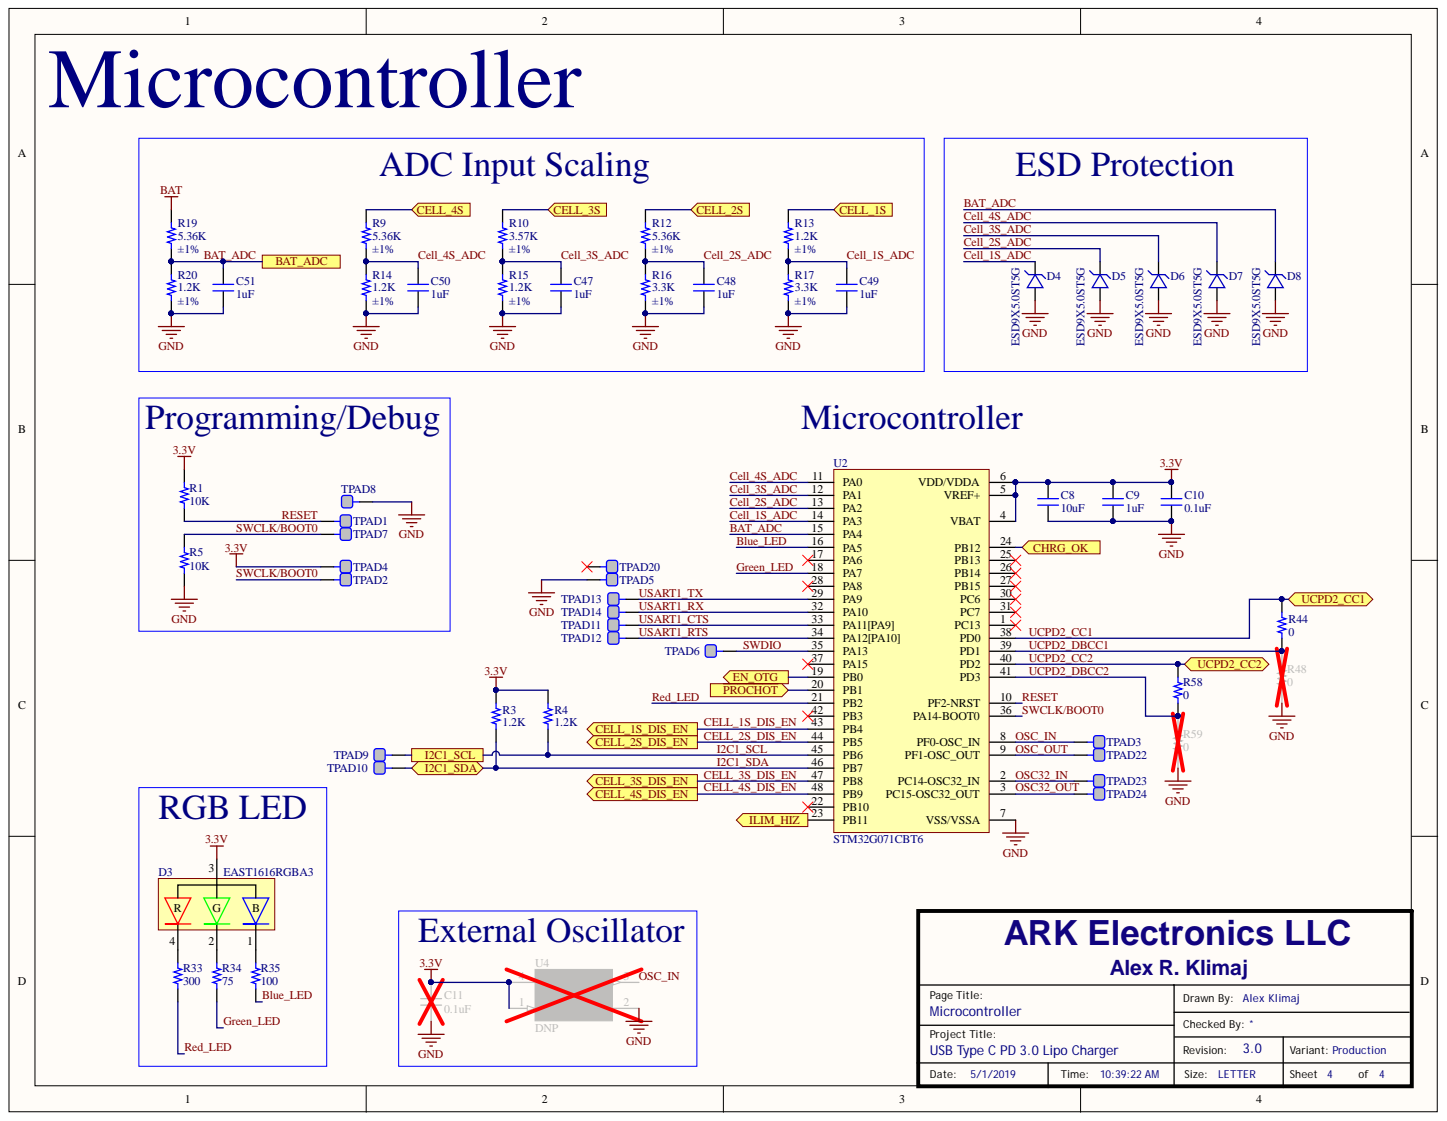
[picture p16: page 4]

5/1/2019 | 10:39:22 AM | Size:

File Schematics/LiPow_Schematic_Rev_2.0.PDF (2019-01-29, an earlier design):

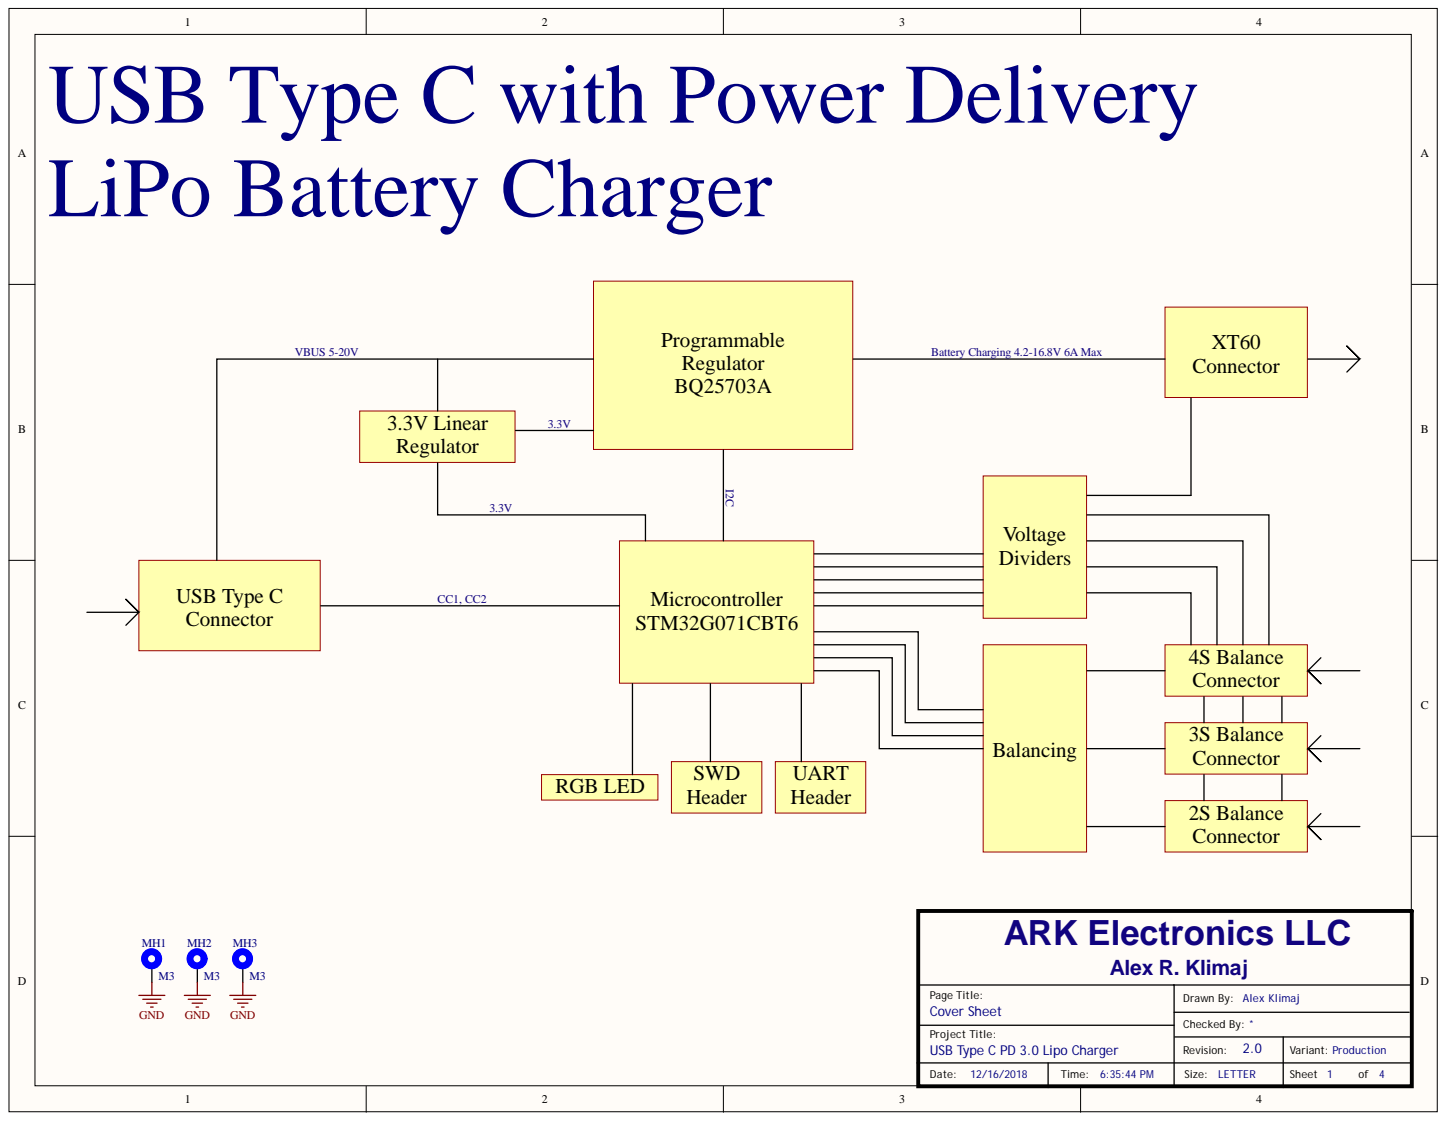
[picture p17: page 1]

USB Type C with Power Delivery
LiPo Battery Charger

Project Title:
USB Type C PD 3.0 Lipo Charger

Revision: | Variant: Production

Date: 12/16/2018 | Time: 6:35:44 PM | Size: LETTER | Sheet of


Connectors, USB PD, and Balancing 32V 5A

ARK Electronics LLC Alex R. Klimaj

R evisio n : 2. | P r odu ctio n

Date : 12/16/2018 | Time : 6:35:44 PM | Size : L E T T E R | Sh e e t o f


SRP

VDDA 7 | | SRN

R52 COMP2 | COMP2 17

R53 | IADPT


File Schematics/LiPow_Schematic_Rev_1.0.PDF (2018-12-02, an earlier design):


USB Type C with Power Delivery
LiPo Battery Charger

USB Type C Connector

Project Title:
USB Type C PD 3.0 Lipo Charger

Revision: | Variant: [No Variations]

Date: 12/1/2018 | Time: 8:41:05 PM | Size: LETTER | Sheet of


Connectors, USB PD, and Balancing 32V 5A

Rev i sion: 1. | Vari ant : [ No V ari a t ions]

Da te: 2/ / | T i me: : : 05 P M | Si ze: LETTER | Sheet of


GND | SRP

R52 COMP2 | COMP2 17

CELL_BATPRESZ

R53 | IADPT


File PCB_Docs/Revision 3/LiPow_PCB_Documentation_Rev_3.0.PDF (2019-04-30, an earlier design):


LiPow
USB C PD Lipo Battery Charger Rev 03
ARK Electronics
Alex Klimaj

View from Top side (Scale 1:1)

View from Front side (Scale 1:1)

View from Back side (Scale 1:1)


Symbol | Count | Hole Size | Plated | Hole Tolerance

3 | 3.40 | Plated | +/-0.13
2 | 2.70 | Plated | +/-0.13
2 | 1.70 | Plated | +/-0.13
2 | 1.40 | Plated | +/-0.13
2 | 1.10 | Plated | +/-0.13
27 | 1.00 | Plated | +/-0.13
2 | 0.85 | Non-Plated | +/-0.13
12 | 0.40 | Plated | +/-0.13
378 | 0.30 | Plated | +/-0.13


Courtyard Bottom (Scale: 1:1) Courtyard Top (Scale: 1:1)

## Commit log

2019-01-29 Added Rev 02 of the Schematic
2019-04-30 Add Rev 3.0 Schematic
2019-04-30 Rev 3.0 Files Added and Naming
    [LiPow_BOM_Rev_3.0.xls]
2019-05-01 Fix Rev 3 schematic DNS not showing
2019-05-29 Add Rev 3 Paste Mask Gerbers
    [LiPow Rev 3.0 Bottom Paste Mask.GBP, LiPow Rev 3.0 Top Paste Mask.GTP]
2019-05-29 Add Case stl's
    [LiPow Bottom Case Rev 0.4.stl, LiPow Top Case Rev 0.4 Debug.stl, LiPow Top Case Rev 0.4.stl]
2019-07-18 Update Top Case To Latest Revision
    [LiPow Top Case Rev 0.4 Debug.stl, LiPow Top Case Rev 0.5 Debug.stl, LiPow Top Case Rev 0.5.stl]
2019-12-20 Add Revision 4 Documents
    [LiPow_BOM_Rev_4.0.xls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]
2020-05-27 Update 3d model with xt60 model. Update case version.
    Update the 3d models and documentation with the real xt60 3d model.
    Update to the latest version of the case. Changes hole sizes and adds clearance for debug headers on the fully enclosed version.
    [LiPow Bottom Case Rev 0.4.stl, LiPow Bottom Case Rev 0.6.stl, LiPow Top Case Rev 0.5.stl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]
2020-10-01 Add CNC and Fan Cases
    [Bottom Case CNC V1.0.step, Bottom Case Fan 1.0.stl, LiPow Bottom Case Rev 0.6.stl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]
